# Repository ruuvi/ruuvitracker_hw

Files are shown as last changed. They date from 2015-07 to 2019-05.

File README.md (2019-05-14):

# RuuviTracker: Open-Source GPS/GSM Positioning Device

### NOTE: RuuviTracker has been rebranded to Ruuvi Node. This repository will be kept online for historical reasons.

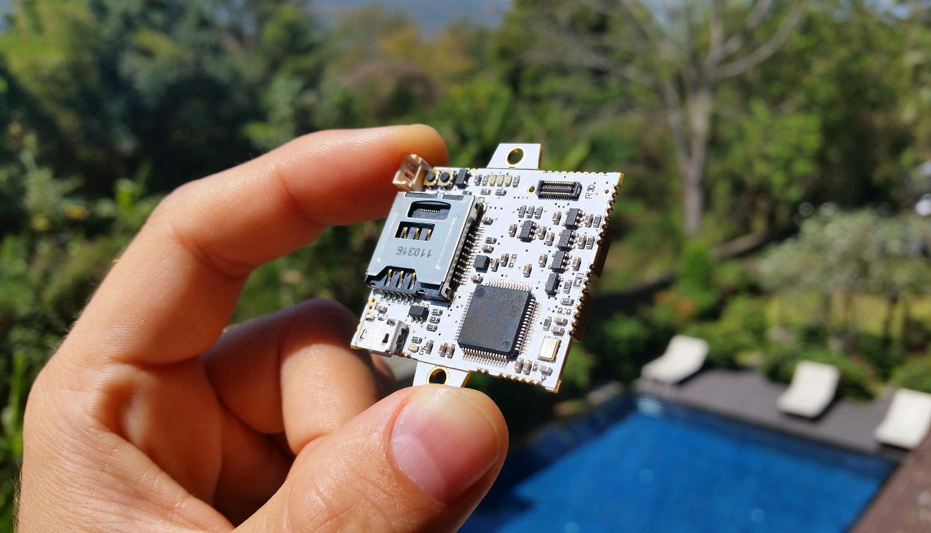
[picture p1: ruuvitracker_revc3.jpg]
RuuviTracker (http://ruuvi.com)


Latest hardware version is Rev.C3. First one was Rev.A1 and then Rev.B1 came out. And after that, Rev.C1 and Rev.C2. Revisions A, B and C are completely different devices.

All the design files are licensed under Attribution-ShareAlike 4.0 International (CC BY-SA 4.0). Copyright Lauri Jämsä, Ruuvi Innovations Ltd. Neither the name of the RuuviTracker nor the names of its contributors may be used to endorse or promote products derived from this project without specific prior written permission. While unofficial products should not have "Ruuvi" in their name, it's okay to describe your product in relation to the Ruuvi projects. For more info, drop us a line: license@ruuvi.com.

https://ruuvi.com

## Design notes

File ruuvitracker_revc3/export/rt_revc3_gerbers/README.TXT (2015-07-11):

Board: RuuviTracker Rev.C3

Board Size: 38.50 x 33.40mm
Material: FR4 High Tg 135C
Layers: 6
Silkscreen: Top & Bottom (black)
Solder masks: Top & Bottom (white)
Plating: Immersion Gold (or HASL if it's easier to assemble)
Thickness: 1.0mm !
Copper thickness: 35um
Paneling (you can decide what's best for you, this is just a suggestion. However, v-cuts are required):
3x2 (v-cuts + routing, see rt_revc2_paneling_info.pdf for help):
 __ __ __ 
|__|__|__|
|__|__|__|

Leadless solderpaste not required. More important that the yeld is 100%!

Minimum clearance: 0.10mm
Minimum trace thickness: 0.15mm
Minimum hole diameter: 0.30mm

Layer files (in correct order):
 
1. F_Cu (Top)
2. Inner4 (Sig1)
3. Inner3 (Sig2)
4. Inner2 (VDD)
5. Inner1 (GND)
6. B_Cu (Bottom)

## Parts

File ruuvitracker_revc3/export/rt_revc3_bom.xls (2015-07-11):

Id | Designator | Package | Quantity | Designation | Assembled? | Supplier and ref
1 | P12 | 005INCH_PINSTRIP_THRUHOLE_2PIN | 1 | 5V_IN | NO
2 | K1 | 53047-0310_3PIN_THRU | 1 | BATTERY |  | 53047-0310 | https://fi.mouser.com/Search/ProductDetail.aspx
3 | P5 | 005INCH_PINSTRIP_THRUHOLE_2PIN | 1 | GSM_SPK | NO
4 | P6 | 005INCH_PINSTRIP_THRUHOLE_2PIN | 1 | GSM_MIC | NO
5 | C1,C2,C3,C4,C5,C7 | SMD_0603_RT | 6 | 220n |  | VJ0603V224MXJPW1BC | http://fi.mouser.com/ProductDetail/Vishay-Vitramon/VJ0603V224MXJPW1BC/
6 | C6,C8,C9,C10,C11,C12,C13,C14,C15,C16,C17,C25,C27,C28,C29,C30,C31 | SMD_0603_RT | 17 | 2u2 |  | GRM188R61A225KE34D | http://fi.mouser.com/ProductDetail/Murata-Electronics/GRM188R61A225KE34D/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
7 | C18,C19 | TANTALUM_D_E_2917 | 2 | 680u |  | TPSE687M006R0045 | https://fi.mouser.com/Search/ProductDetail.aspx
8 | C20 | SMD_0603_RT | 1 | GPSCAP1 | NO
9 | C21 | SMD_0603_RT | 1 | GSMCAP1 | NO
10 | C22 | SMD_0603_RT | 1 | GPSCAP2 | NO
11 | C23 | SMD_0603_RT | 1 | GSMCAP2 | NO
12 | C24,C26 | SMD_0603_RT | 2 | 10p |  | VJ0603A100JXACW1BC | https://fi.mouser.com/Search/ProductDetail.aspx
13 | D1 | LED_SMD-0603 | 1 | LED_RED |  | VLMO1300-GS08 | http://fi.mouser.com/ProductDetail/Vishay/VLMO1300-GS08/
14 | D2,D3 | LED_SMD-0603 | 2 | LED_GREEN |  | VLMG1300-GS08 | http://fi.mouser.com/ProductDetail/Vishay/VLMG1300-GS08/
15 | D4 | LED_SMD-0603 | 1 | LED_CHG |  | VLMS1300-GS08 | http://fi.mouser.com/ProductDetail/Vishay-Semiconductors/VLMS1300-GS08/
16 | J1 | MICROUSB_B_10118192-0001LF | 1 | USB_MICRO_B |  | 10118192-0001LF | https://fi.mouser.com/Search/ProductDetail.aspx
17 | Q1 | SOT23-GDS | 1 | MOSFET_P |  | NX2301P,215 | https://fi.mouser.com/Search/ProductDetail.aspx
18 | R1,R2,R3,R4,R13 | SMD_0603_RT | 5 | 47k |  | ERJ-3EKF4702V | http://fi.mouser.com/ProductDetail/Panasonic/ERJ-3EKF4702V/
19 | R5,R6,R17 | SMD_0603_RT | 3 | 10 |  | ERJ-3GEYJ100V | http://fi.mouser.com/ProductDetail/Panasonic/ERJ-3GEYJ100V/
20 | R7,R22 | SMD_0603_RT | 2 | 2k |  | ERJ-3GEYJ202V | http://fi.mouser.com/ProductDetail/Panasonic/ERJ-3GEYJ202V/
21 | R8,R9,R10,R21 | SMD_0603_RT | 4 | 330 |  | ERJ-3GEYJ331V | http://fi.mouser.com/ProductDetail/Panasonic/ERJ-3GEYJ331V/?qs=sGAEpiMZZMu61qfTUdNhGzRxdwze5h8ZXotD4TVKeq8%3d
22 | R11,R12,R23,R24 | SMD_0603_RT | 4 | 4k7 |  | ERJ-3GEYJ472V | http://fi.mouser.com/ProductDetail/Panasonic/ERJ-3GEYJ472V/?qs=sGAEpiMZZMvdGkrng054txqI5fKHz4ddS7gybnWqBSI%3d
23 | R14, C32 | SMD_0603_RT | 1 | NA | NO
24 | R18 | SMD_0603_RT | 1 | GPSRES (0ohm) |  | RK73Z1JTTD | http://fi.mouser.com/ProductDetail/KOA-Speer/RK73Z1JTTD/
25 | R19 | SMD_0603_RT | 1 | GSMRES1 | NO
26 | R20 | SMD_0603_RT | 1 | GSMRES2 | NO
27 | SW1 | SKSGPAE010 | 1 | PUSH_BUTTON |  | SKSGPAE010 | https://fi.mouser.com/Search/ProductDetail.aspx
28 | U1 | LQFP-64 | 1 | STM32F10XXX_LQFP64 |  | STM32F405RGT6 | https://fi.mouser.com/Search/ProductDetail.aspx
29 | U3 | DFN_10PIN_2X2MM | 1 | MMA8652FC |  | MMA8652FCR1 | https://fi.mouser.com/Search/ProductDetail.aspx
30 | U7 | SOT23-6 | 1 | TPD2S017 |  | TPD2S017DBVR | https://fi.mouser.com/Search/ProductDetail.aspx
31 | X1 | ABM8G_3_2X2_5MM_4PIN_CRYSTAL | 1 | 8-24MHZ |  | FA-238 16.0000MB-K3 | http://fi.mouser.com/ProductDetail/Epson-Toyocom/FA-238-160000MB-K3/
32 | P7 | 005INCH_PINSTRIP_THRUHOLE_1PIN | 1 | GSM_ANT | NO
33 | U2 | SIM968_RECT | 1 | SIM968 |  | SIM968
34 | P2 | UFL-R-SMT | 1 | GPS_CONN |  | General U.FL SMD
35 | P3 | UFL-R-SMT | 1 | GSM_CONN |  | General U.FL SMD
36 | P8 | 1MM_THRUHOLE_1PIN | 1 | ALIGNMENT | NO
37 | U9 | COMBO_CARDSLOT_MES3051_OPTIMIZED | 1 | MICROSD_SIM_COMBO |  | AIO2X-21605BT00 (Kingfont)
38 | U4,U5,U6,U11 | SOT23-5 | 4 | TPS783XX |  | TPS78330DDCR | https://fi.mouser.com/Search/ProductDetail.aspx
39 | U8 | SOT23-5 | 1 | MCP73831 |  | MCP73831T-2ACI/OT | https://fi.mouser.com/Search/ProductDetail.aspx
40 | P4,P9,P10,P11 | TP_SMD_08MM | 4 | FIDU | NO
41 | P13,P14,P15,P16,P17,P18,P19,P20,P21,P22,P23,P24,P25,P26,P27,P28,P29,P30,P31,P32,P33,P34,P35,P36,P37,P38,P39,P40,P41,P42,P43,P44,P45,P46,P47 | 005INCH_PINSTRIP_THRUHOLE_1PIN | 35 | CONN_1 | NO
43 | SJ2 | SOLDER_JUMPER_2_PASTE12 | 1 | SOLDER_JUMPER_2_PASTE1&2 | NO
44 | SJ3,SJ1 | SOLDER_JUMPER_3_PASTE12 | 2 | SOLDER_JUMPER_3_PASTE1&2 | NO
45 | P48,P49 | 3MM_PLATED_HOLE | 2 | HOLE | NO
46 | P1 | DF37NB-24DS-04V | 1 | IPROTOXI_CONN |  | DF37NB-24DS-0.4V(51) | https://fi.mouser.com/Search/ProductDetail.aspx
47 | G*** | RUUVITRACKER_LOGO_035INCH_TOPMASK | 1 | RUUVITRACKER_LOGO_035INCH_TOPMASK | NO
45 | SW2 | SKSGPAE010 | 1 | BOOT0_BUT |  | SKSGPAE010

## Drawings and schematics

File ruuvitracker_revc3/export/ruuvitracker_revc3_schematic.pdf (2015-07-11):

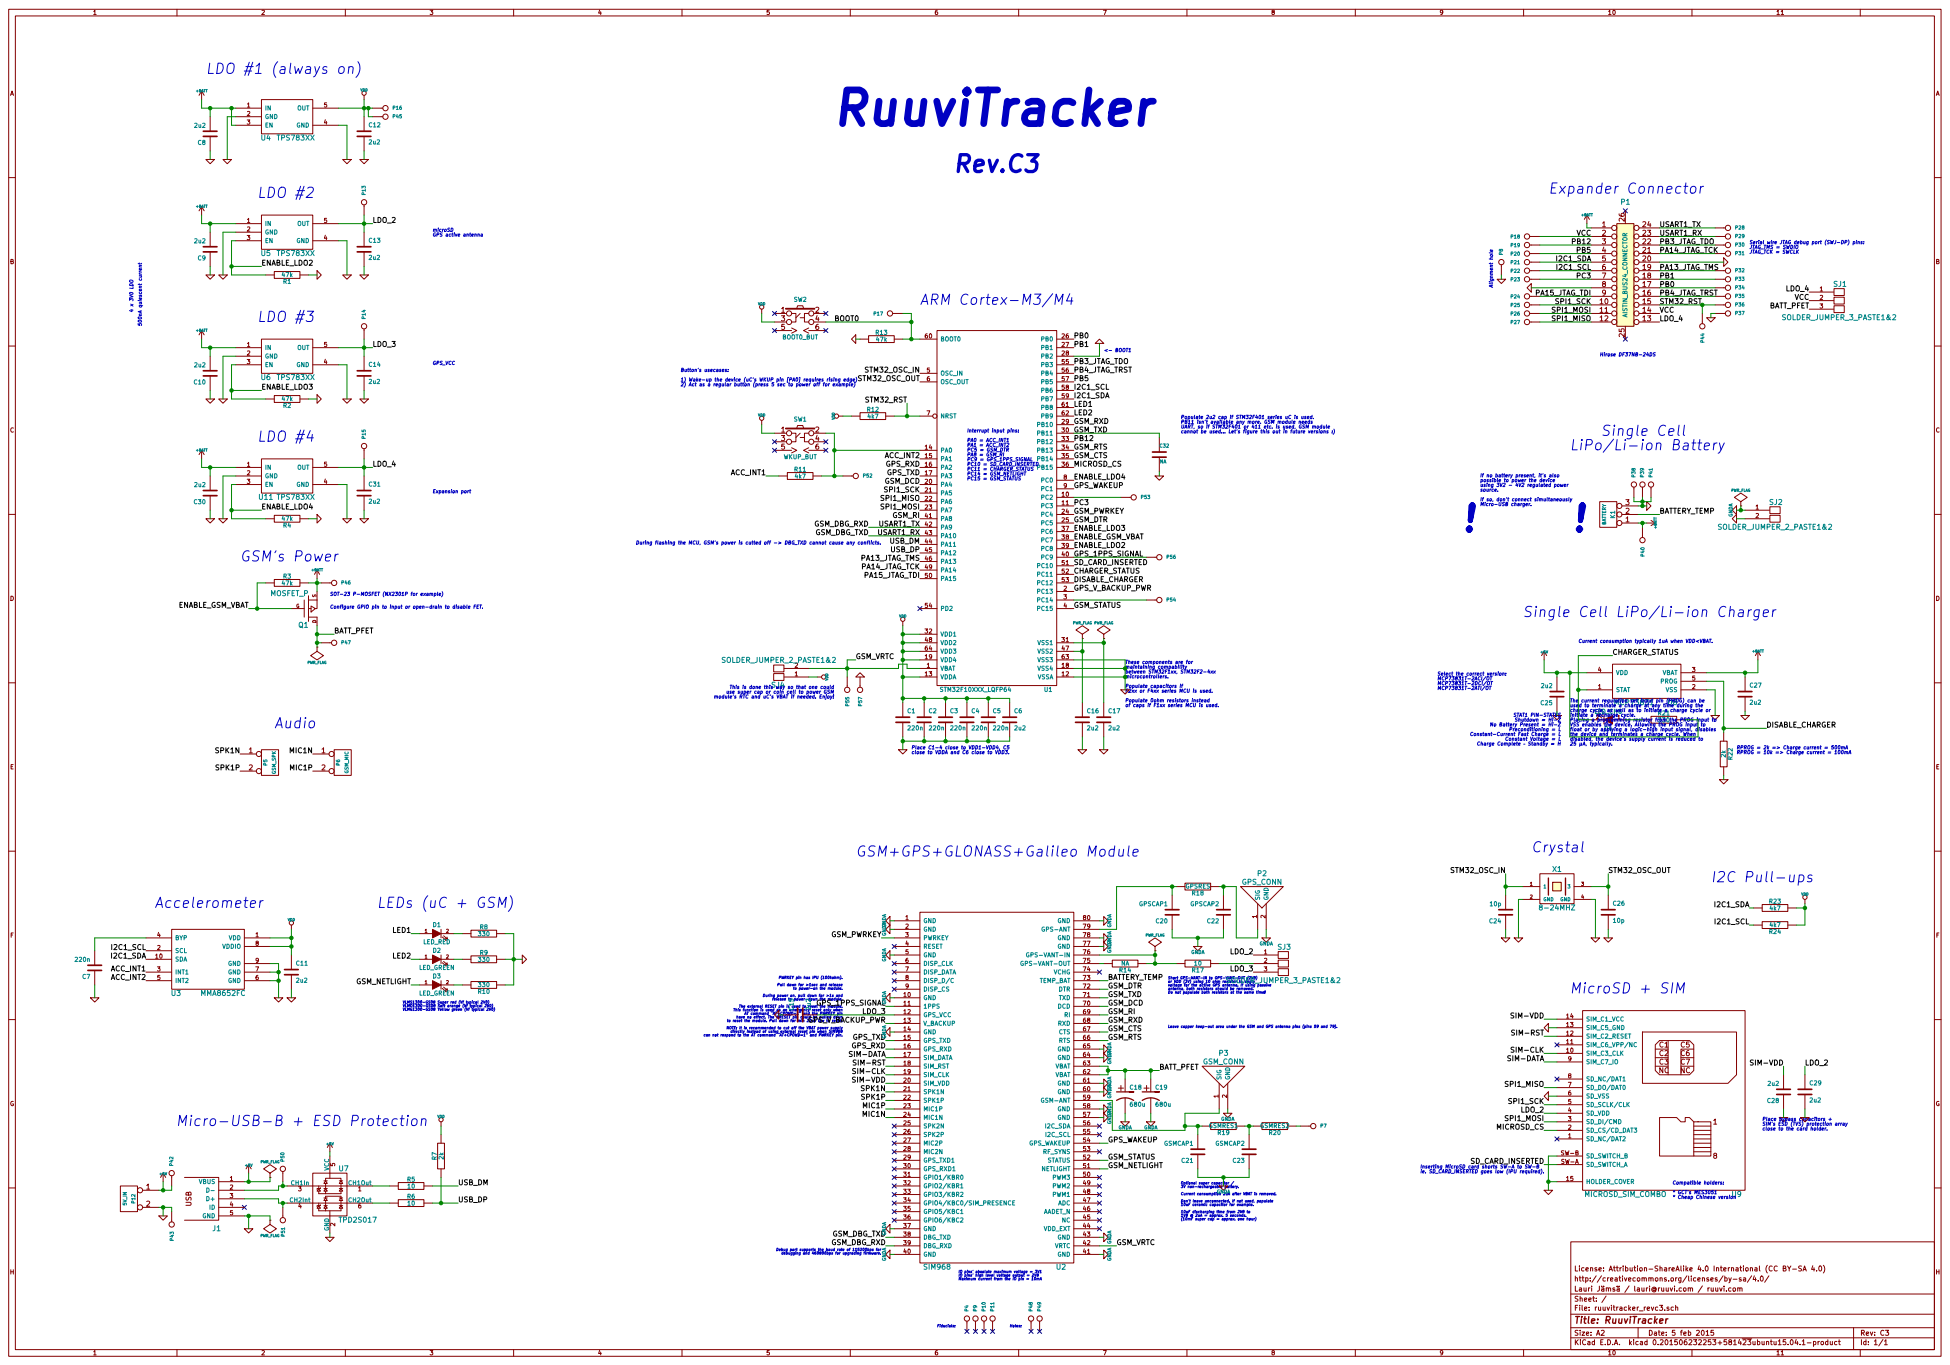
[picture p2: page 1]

SOT-23 P-MOSFET (NX2301P for example) LDO #2

LDO_2
microSD GPS active antenna GPS_VCC

VCC P8 Alignment hole Select the correct version: MCP73831T-2ACI/OT MCP73831T-2DCI/OT MCP73831T-2ATI/OT P4P9P10 P11

Serial wire JTAG debug port (SWJ-DP) pins: JTAG_TMS = SWDIO

4k7 BOOT0
close to VDDA and C6 close to VDD3. ACC_INT2

Populate 2u2 cap if STM32F401 series uC is used. PB11 isn't available any more. GSM module needs UART, so if STM32F401 or 411 etc. is used, GSM module

Single Cell
LiPo/Li-ion Battery 123 K1 BATTERY

GSM_RTS
GSM_CTS
of caps if F1xx series MCU is used. MICROSD_CS

If no battery present, it's also
possible to power the device
using 3V2 - 4V2 regulated power source.

If so, don't connect simultaneously Micro-USB charger.

Single Cell LiPo/Li-ion Charger

These components are for maintaining compability between STM32F1xx, STM32F2-4xx microcontrollers. Populate capacitors if F2xx or F4xx series MCU is used. Populate 0ohm resistors instead

use super cap or coin cell to power GSM

The current regulation set input pin (PROG) can be
used to terminate a charge at any time during the
charge cycle, as well as to initiate a charge cycle or
initiate a recharge cycle. Placing a programming resistor from the PROG input to VSS enables the device. Allowing the PROG input to

float or by applying a logic-high input signal, disables
the device and terminates a charge cycle. When
disabled, the devices supply current is reduced to

GSM+GPS+GLONASS+Galileo Module

VLMS1300-GS08 Super red (Vf typical 2V0) VLMO1300-GS08 Soft orange (Vf typical 2V0) VLMG1300-GS08 Yellow green (Vf typical 2V0) LEDs (uC + GSM)

antenna, both resistors should be removed. Do not populate both resistors at the same time! R14 NA GSM_DCD
BATTERY_TEMP
GSM_DTR
GSM_TXD

PWRKEY pin has IPU (100kohm). Pull down for >1sec and release

Short GPS-VANT-IN to GPS-VANT-OUT (2V8) or VDD (3V) using 10 ohm resistor to apply
voltage for the active GPS antenna. If using passive

to power-on the module. During power on, pull down for >1s and

release to power-down the module. The external RESET pin is used to reset the module. This function is used as an emergency reset only when AT command AT+CPOWD=1 and the PWRKEY pin

have no effect. The NRESET pin could be pulled down
to reset the module. Pull down for min 20us low to reset. NOTE: It is recommended to cut off the VBAT power supply directly instead of using external reset pin when SIM968

Leave copper keep-out area under the GSM and GPS antenna pins (pins 59 and 79). GSM_NETLIGHT

close to the card holder. C28

VDD Micro-USB-B + ESD Protection

Place bypass capacitors + SIM's ESD (TVS) protection array

Inserting MicroSD card shorts SW-A to SW-B

10uF ceramic capacitor for example. 10uF discharging time from 2V8 to

Debug port supports the baud rate of 115200bps for debugging and 460800bps for upgrading firmware.

IO pins' absolute maximum voltage = 3V1

License: Attribution-ShareAlike 4.0 International (CC BY-SA 4.0)
http://creativecommons.org/licenses/by-sa/4.0/
File: ruuvitracker_revc3.sch Sheet: / Lauri Jämsä / lauri@ruuvi.com / ruuvi.com

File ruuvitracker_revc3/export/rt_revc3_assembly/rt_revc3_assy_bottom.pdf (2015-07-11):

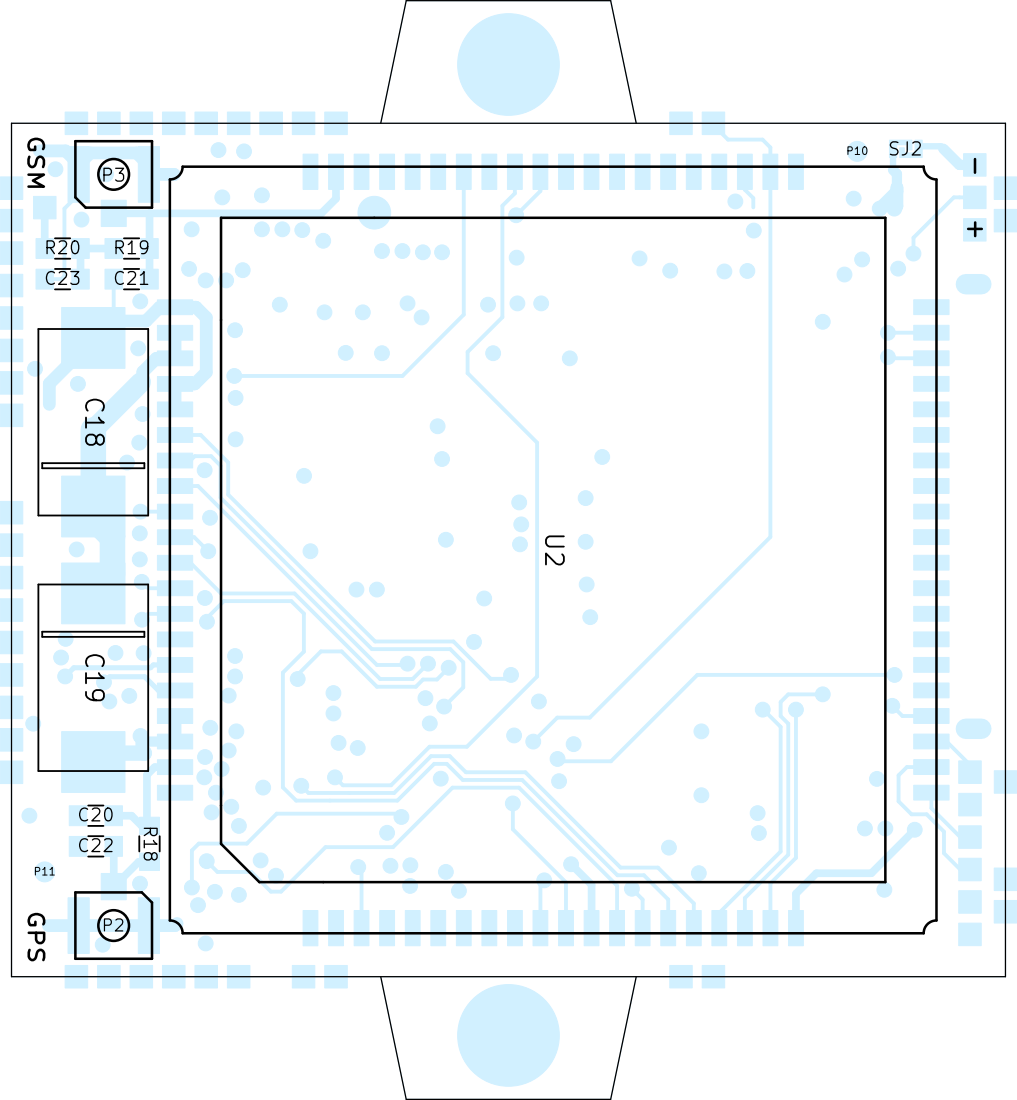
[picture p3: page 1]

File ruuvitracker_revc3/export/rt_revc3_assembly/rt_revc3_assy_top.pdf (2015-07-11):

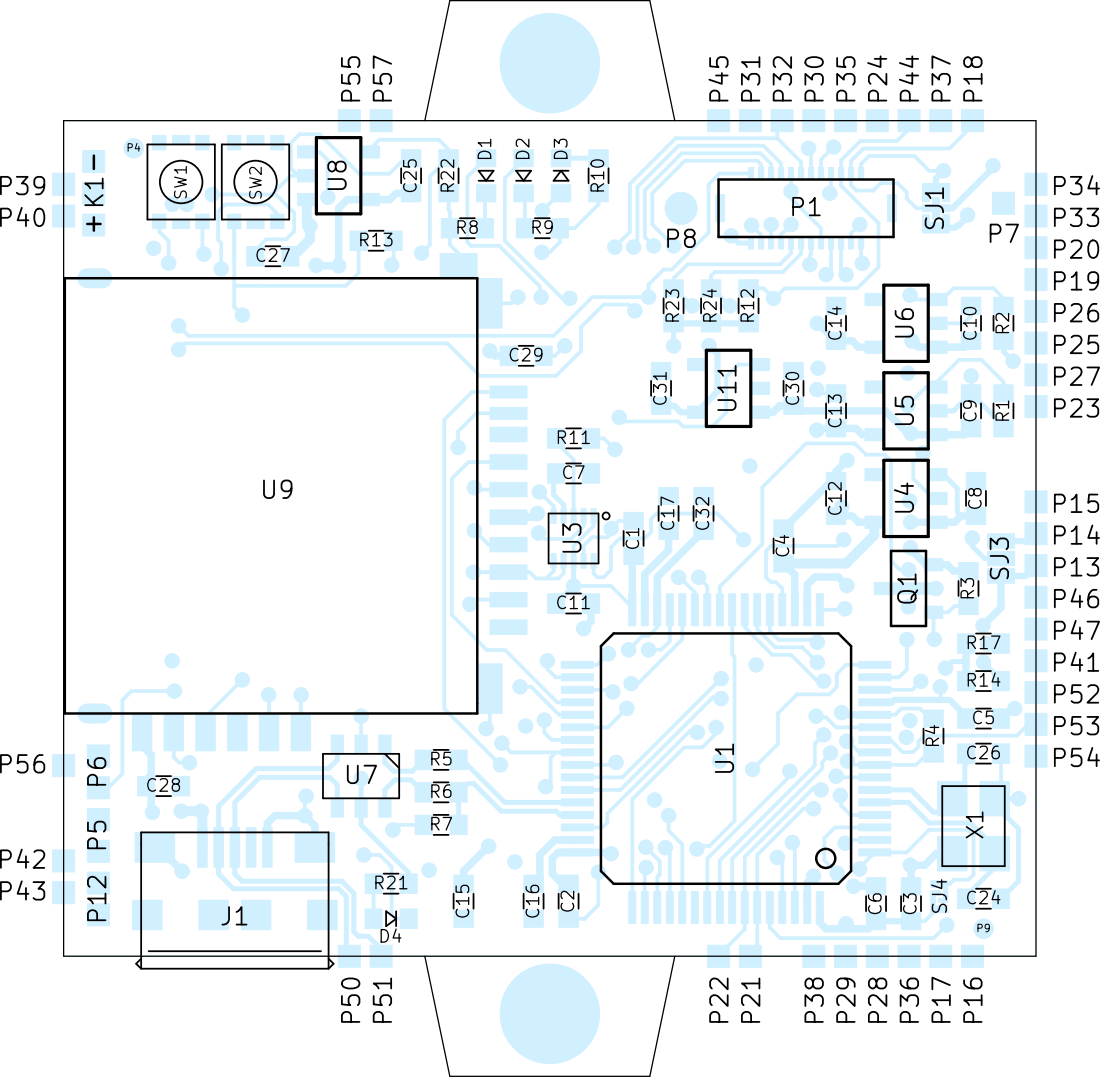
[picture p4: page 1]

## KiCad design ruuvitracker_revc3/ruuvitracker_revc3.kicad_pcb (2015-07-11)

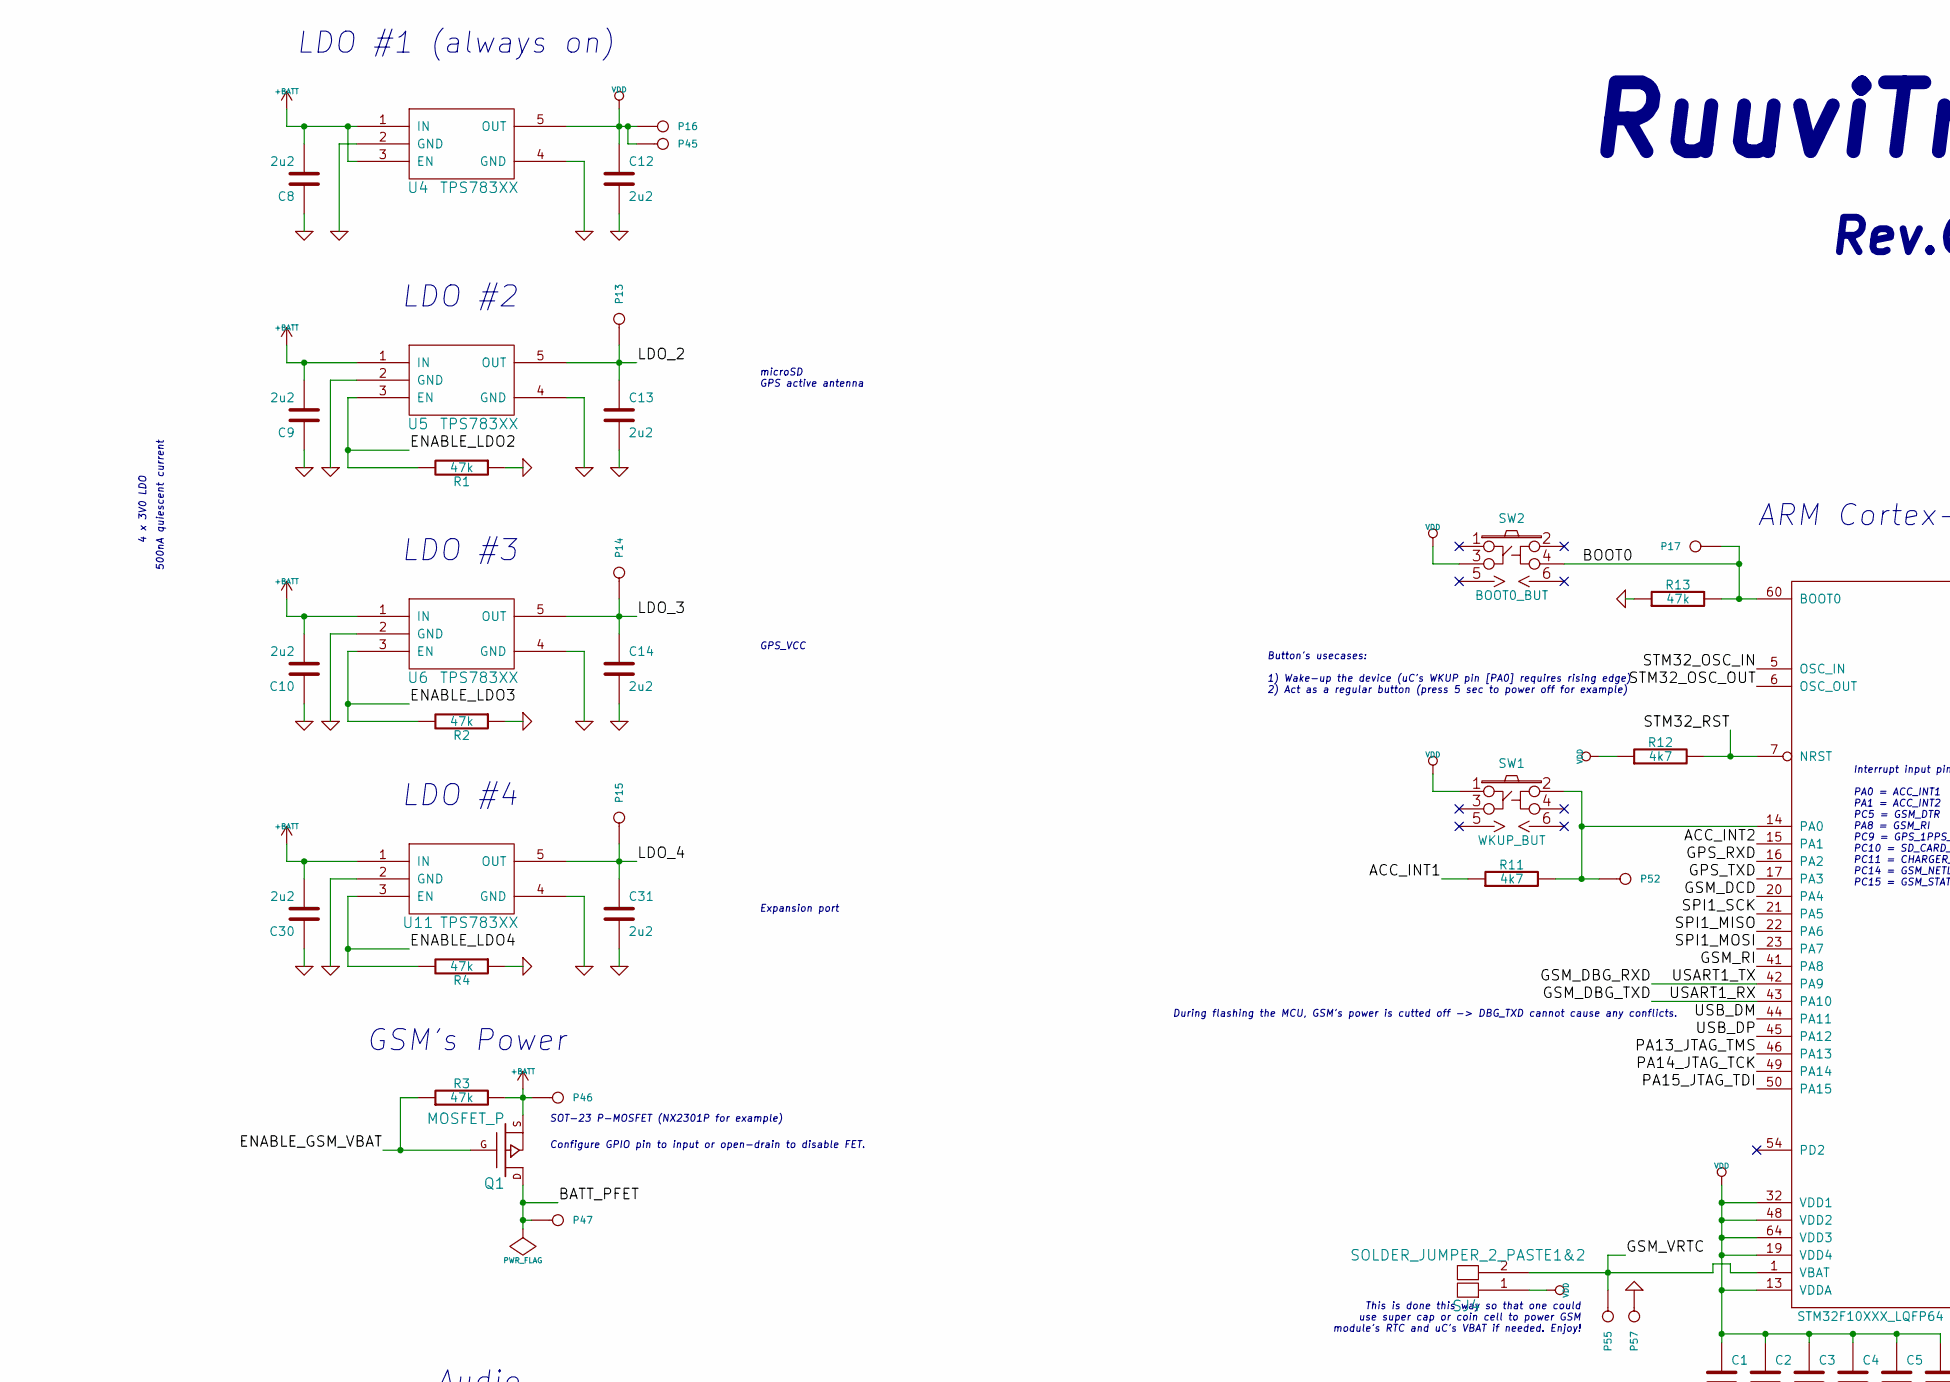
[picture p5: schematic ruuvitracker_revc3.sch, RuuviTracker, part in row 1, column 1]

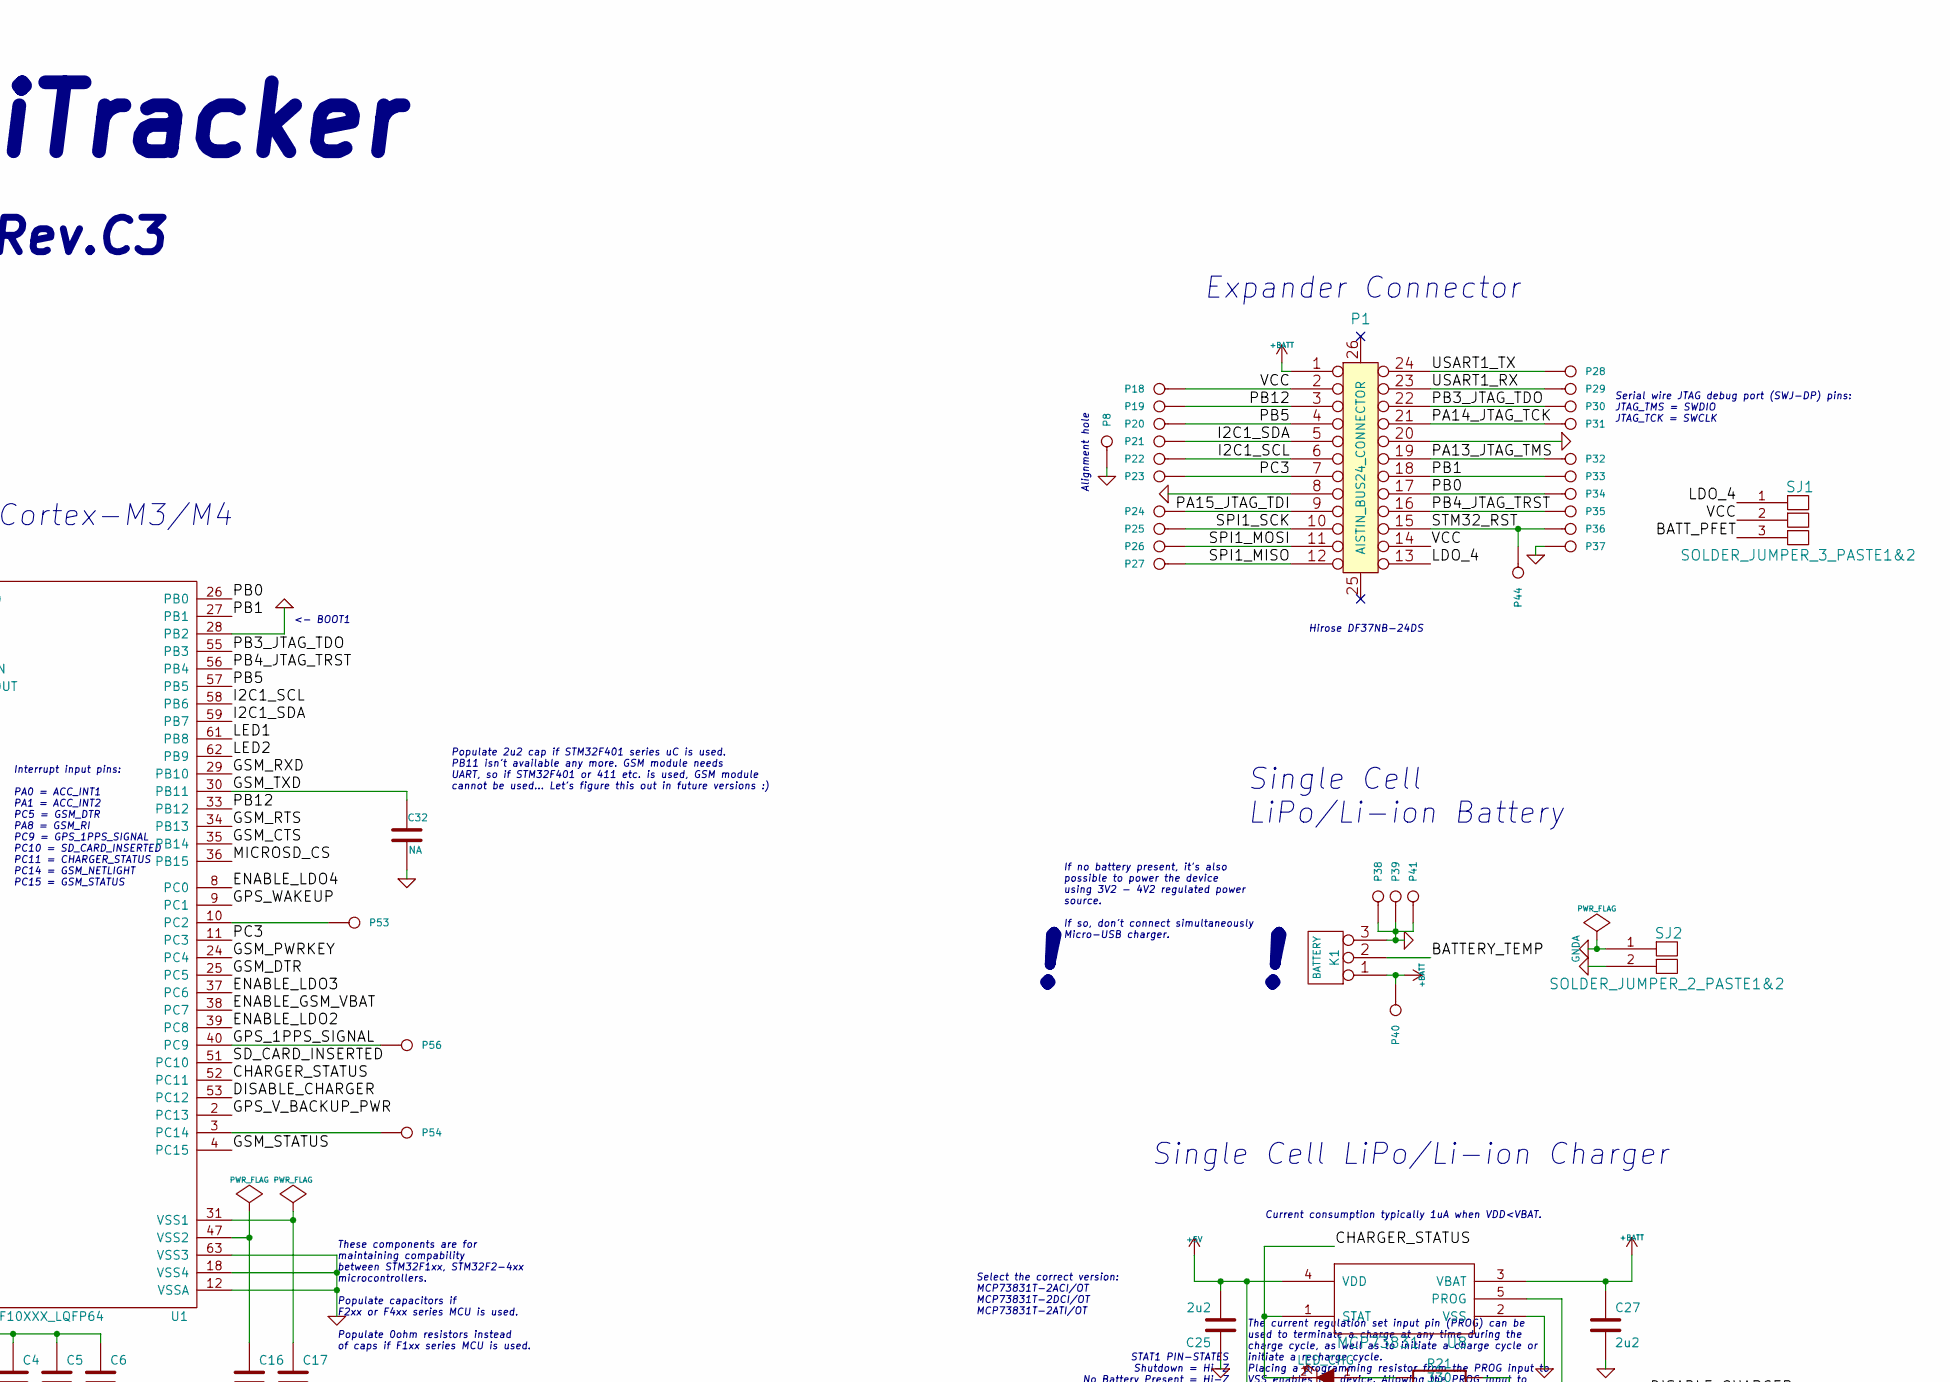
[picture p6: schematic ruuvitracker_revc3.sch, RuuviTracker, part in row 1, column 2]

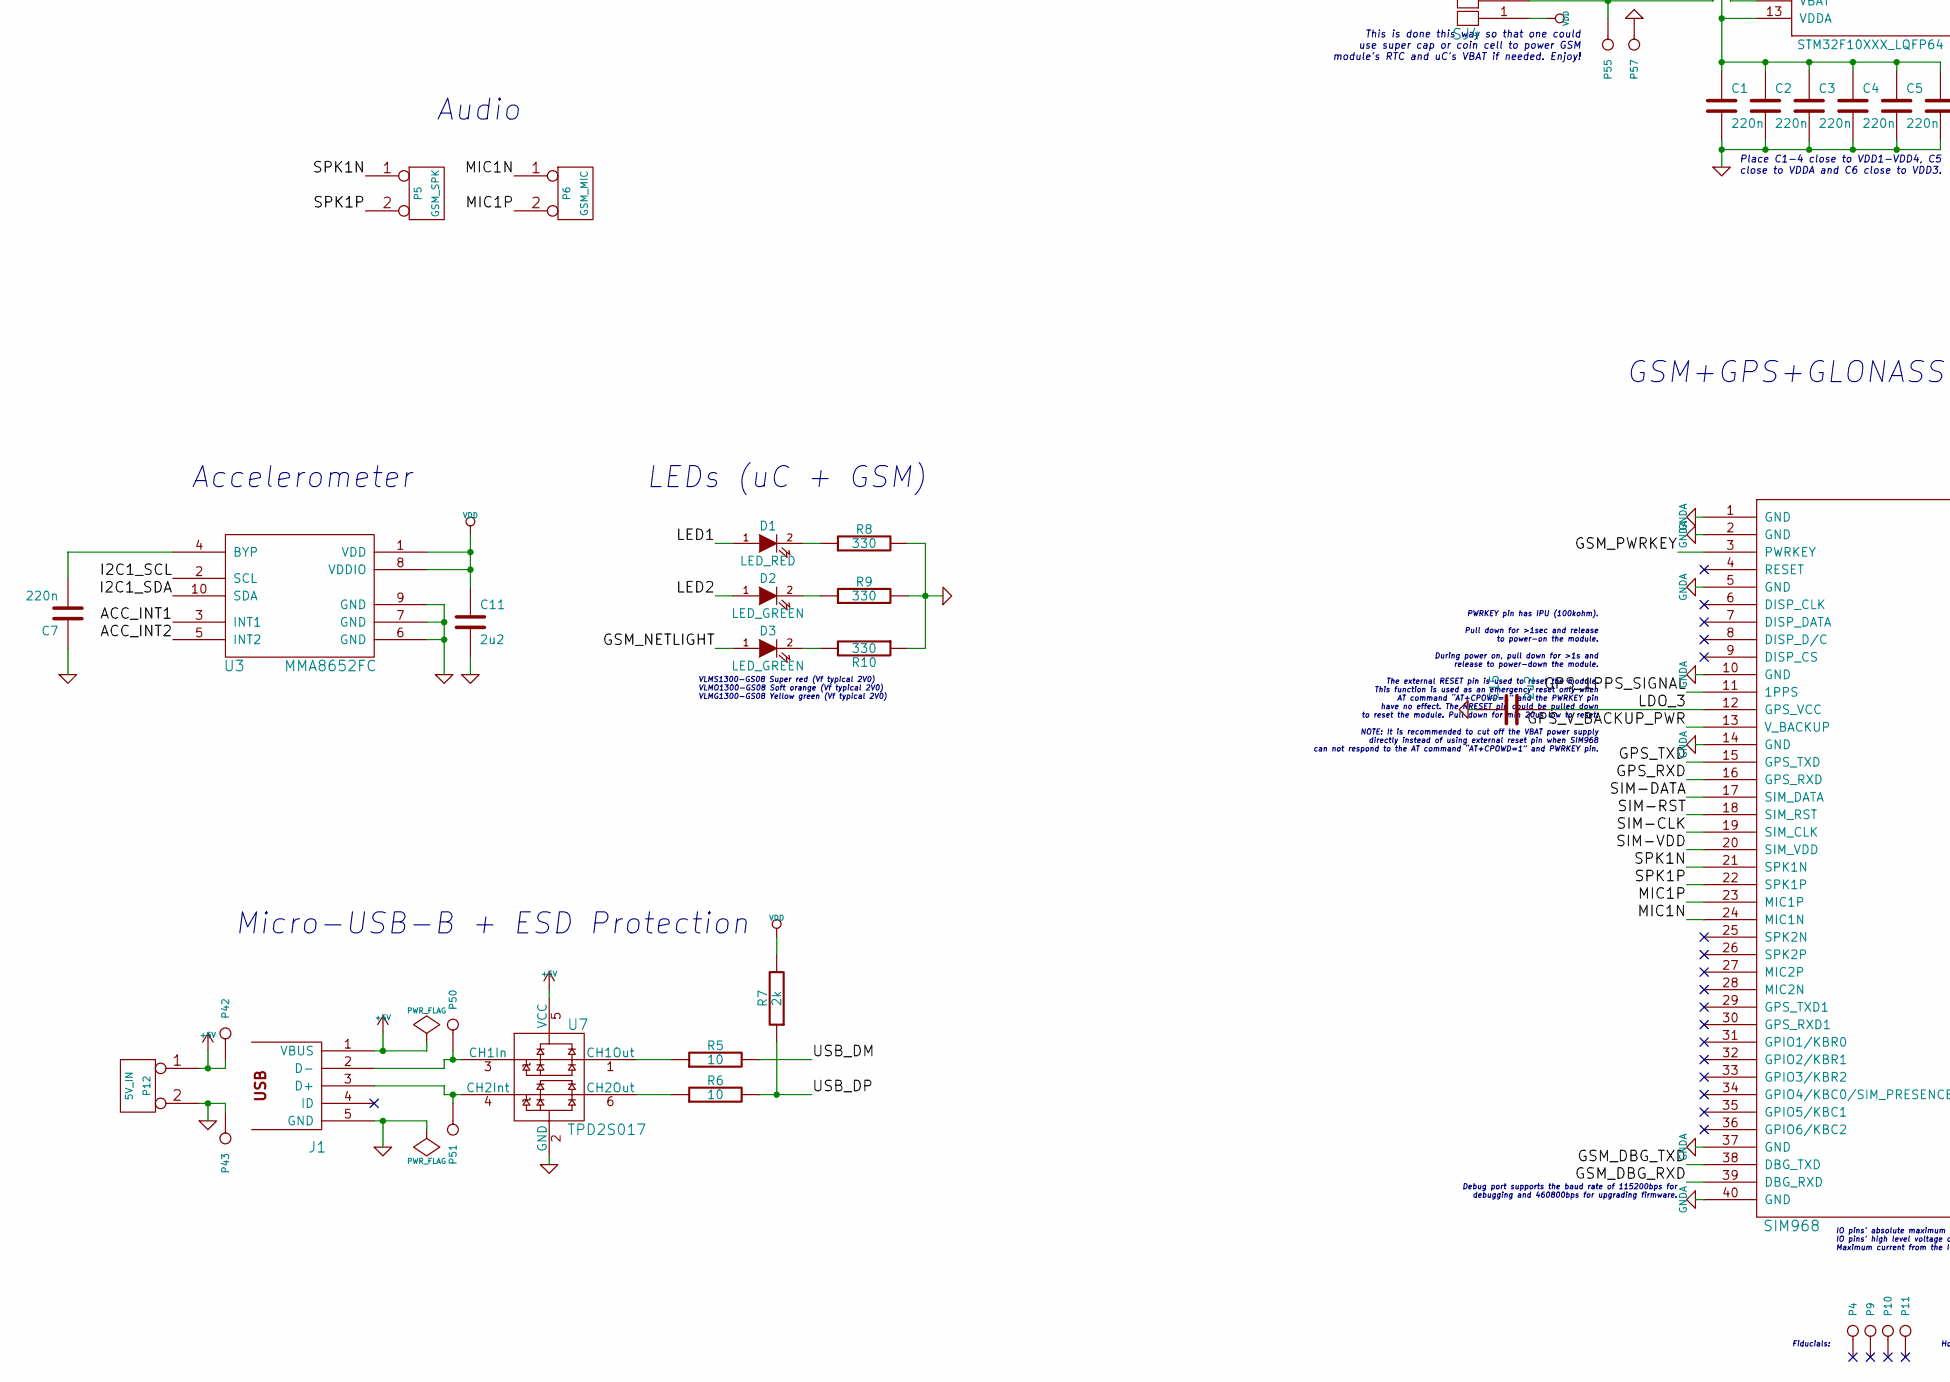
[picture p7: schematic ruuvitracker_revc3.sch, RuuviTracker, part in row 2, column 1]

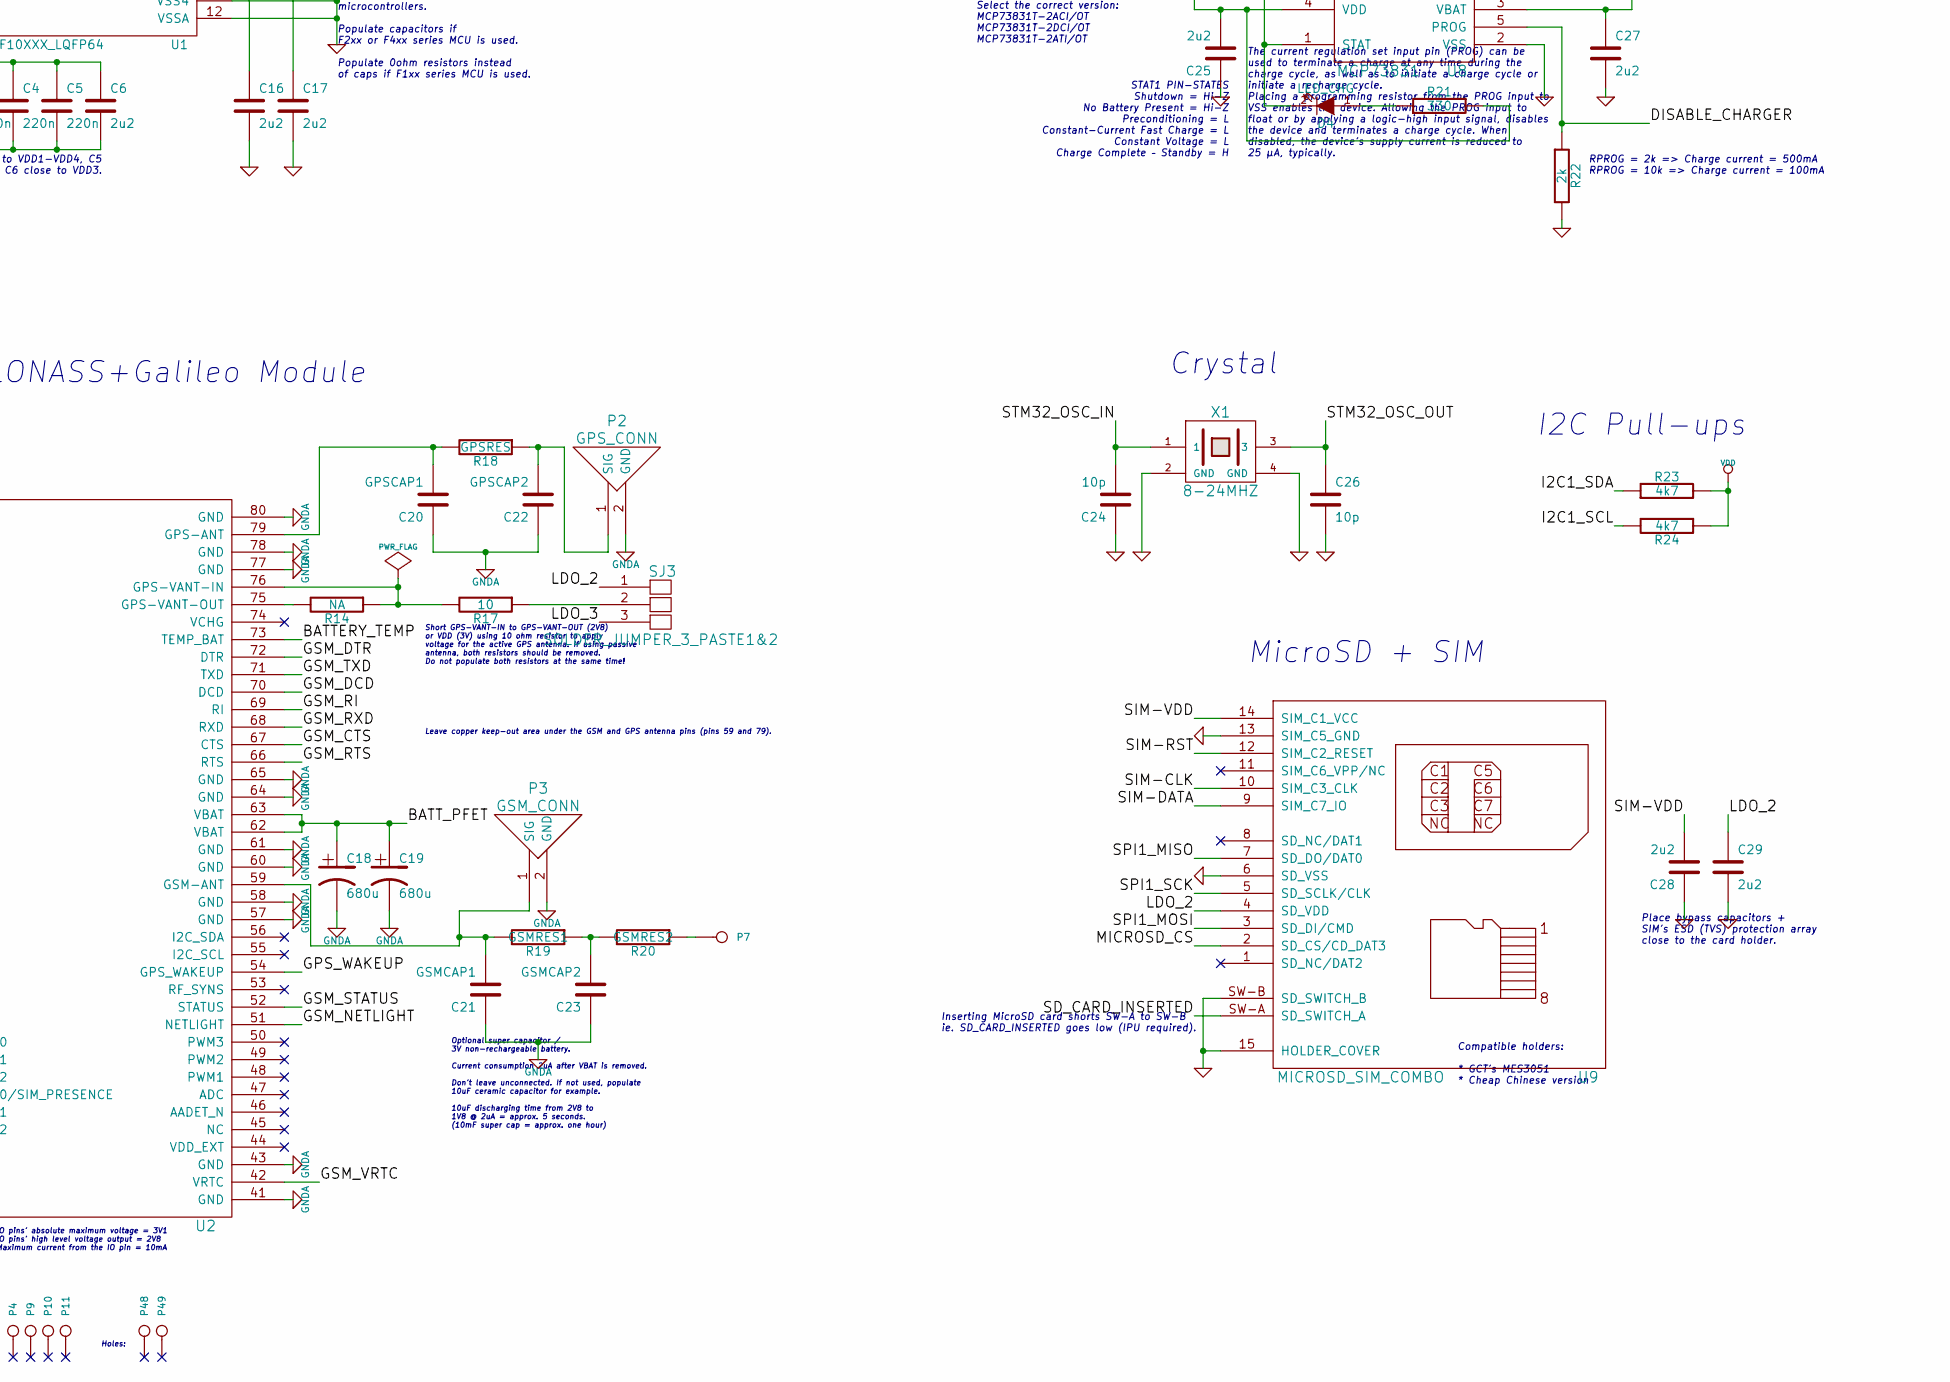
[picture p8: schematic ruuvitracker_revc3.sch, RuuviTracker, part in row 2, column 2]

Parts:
C1, C2, C3, C4, C5, C7: 220n
C6, C8, C9, C10, C11, C12, C13, C14, C15, C16, C17, C25, C27, C28, C29, C30, C31: 2u2
C18, C19: 680u
C20: GPSCAP1
C21: GSMCAP1
C22: GPSCAP2
C23: GSMCAP2
C24, C26: 10p
C32: NA
D1: LED_RED
D2, D3: LED_GREEN
D4: LED_CHG
J1: USB_MICRO_B
K1: BATTERY
P1: AISTIN_BUS24_CONNECTOR
P2: GPS_CONN
P3: GSM_CONN
P4, P9, P10, P11: FIDU
P5: GSM_SPK
P6: GSM_MIC
P7: GSM_ANT
P8: ALIGNMENT
P12: 5V_IN
P13, P14, P15, P16, P17, P18, P19, P20, P21, P22, P23, P24, P25, P26, P27, P28, P29, P30, P31, P32, P33, P34, P35, P36, P37, P38, P39, P40, P41, P42, P43, P44, P45, P46, P47, P50, P51, P52, P53, P54, P55, P56, P57: CONN_1
P48, P49: HOLE
Q1: MOSFET_P
R1, R2, R3, R4, R13: 47k
R5, R6, R17: 10
R7, R22: 2k
R8, R9, R10, R21: 330
R11, R12, R23, R24: 4k7
R14: NA
R18: GPSRES
R19: GSMRES1
R20: GSMRES2
SJ1, SJ3: SOLDER_JUMPER_3_PASTE1&2
SJ2, SJ4: SOLDER_JUMPER_2_PASTE1&2
SW1: WKUP_BUT
SW2: BOOT0_BUT
U1: STM32F10XXX_LQFP64
U2: SIM968
U3: MMA8652FC
U4, U5, U6, U11: TPS783XX
U7: TPD2S017
U8: MCP73831
U9: MICROSD_SIM_COMBO
X1: 8-24MHZ

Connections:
+5V: C25.2, J1.1 (VBUS), P12.1, P42.1, R21.2, U7.5 (VCC), U8.4 (VDD)
+BATT: C8.2, C9.2, C10.2, C27.1, C30.2, K1.1, P1.1, P40.1, P46.1, Q1.S, R3.2, U4.1 (IN), U4.3 (EN), U5.1 (IN), U6.1 (IN), U8.3 (VBAT), U11.1 (IN)
/ACC_INT1: R11.1, U3.3 (INT1)
/ACC_INT2: U1.15 (PA1), U3.5 (INT2)
/BATTERY_TEMP: K1.2 (PM), U2.73 (TEMP_BAT)
/BATT_PFET: C18.1, C19.1, P47.1, Q1.D, SJ1.3, U2.62 (VBAT), U2.63 (VBAT)
/BOOT0: P17.1, R13.2, SW2.4, U1.60 (BOOT0)
/CHARGER_STATUS: D4.2 (K), U1.52 (PC11), U8.1 (STAT)
/DISABLE_CHARGER: R22.1, U1.53 (PC12), U8.5 (PROG)
/ENABLE_GSM_VBAT: Q1.G, R3.1, U1.38 (PC7)
/ENABLE_LDO2: R1.2, U1.39 (PC8), U5.3 (EN)
/ENABLE_LDO3: R2.2, U1.37 (PC6), U6.3 (EN)
/ENABLE_LDO4: R4.2, U1.8 (PC0), U11.3 (EN)
/GPS_1PPS_SIGNAL: P56.1, U1.40 (PC9), U2.11 (1PPS)
/GPS_RXD: U1.16 (PA2), U2.16 (GPS_RXD)
/GPS_TXD: U1.17 (PA3), U2.15 (GPS_TXD)
/GPS_V_BACKUP_PWR: U1.2 (PC13), U2.13 (V_BACKUP)
/GPS_WAKEUP: U1.9 (PC1), U2.54 (GPS_WAKEUP)
/GSM_CTS: U1.35 (PB14), U2.67 (CTS)
/GSM_DBG_RXD: P1.24, P28.1, U1.42 (PA9), U2.39 (DBG_RXD)
/GSM_DBG_TXD: P1.23, P29.1, U1.43 (PA10), U2.38 (DBG_TXD)
/GSM_DCD: U1.20 (PA4), U2.70 (DCD)
/GSM_DTR: U1.25 (PC5), U2.72 (DTR)
/GSM_NETLIGHT: D3.1 (A), U2.51 (NETLIGHT)
/GSM_PWRKEY: U1.24 (PC4), U2.3 (PWRKEY)
/GSM_RI: U1.41 (PA8), U2.69 (RI)
/GSM_RTS: U1.34 (PB13), U2.66 (RTS)
/GSM_RXD: U1.29 (PB10), U2.68 (RXD)
/GSM_STATUS: U1.4 (PC15), U2.52 (STATUS)
/GSM_TXD: C32.1, U1.30 (PB11), U2.71 (TXD)
/GSM_VRTC: P55.1, SJ4.2, U1.1 (VBAT), U2.42 (VRTC)
/I2C1_SCL: P1.6, P22.1, R24.2, U1.58 (PB6), U3.2 (SCL)
/I2C1_SDA: P1.5, P21.1, R23.1, U1.59 (PB7), U3.10 (SDA)
/LDO_2: C13.1, C29.1, P13.1, SJ3.1, U5.5 (OUT), U9.4 (SD_VDD)
/LDO_3: C14.1, C15.2, P14.1, SJ3.3, U2.12 (GPS_VCC), U6.5 (OUT)
/LDO_4: C31.1, P1.13, P15.1, SJ1.1, U11.5 (OUT)
/LED1: D1.1 (A), U1.61 (PB8)
/LED2: D2.1 (A), U1.62 (PB9)
/MIC1N: P6.1, U2.24 (MIC1N)
/MIC1P: P6.2 (PM), U2.23 (MIC1P)
/MICROSD_CS: U1.36 (PB15), U9.2 (SD_CS/CD_DAT3)
/PA13_JTAG_TMS: P1.19, P32.1, U1.46 (PA13)
/PA14_JTAG_TCK: P1.21, P31.1, U1.49 (PA14)
/PA15_JTAG_TDI: P1.9, P24.1, U1.50 (PA15)
/PB0: P1.17, P34.1, U1.26 (PB0)
/PB1: P1.18, P33.1, U1.27 (PB1)
/PB3_JTAG_TDO: P1.22, P30.1, U1.55 (PB3)
/PB4_JTAG_TRST: P1.16, P35.1, U1.56 (PB4)
/PB5: P1.4, P20.1, U1.57 (PB5)
/PB12: P1.3, P19.1, U1.33 (PB12)
/PC3: P1.7, P23.1, U1.11 (PC3)
/SD_CARD_INSERTED: U1.51 (PC10), U9.SW-A (SD_SWITCH_A)
/SIM-CLK: U2.19 (SIM_CLK), U9.10 (SIM_C3_CLK)
/SIM-DATA: U2.17 (SIM_DATA), U9.9 (SIM_C7_IO)
/SIM-RST: U2.18 (SIM_RST), U9.12 (SIM_C2_RESET)
/SIM-VDD: C28.2, U2.20 (SIM_VDD), U9.14 (SIM_C1_VCC)
/SPI1_MISO: P1.12, P27.1, U1.22 (PA6), U9.7 (SD_DO/DAT0)
/SPI1_MOSI: P1.11, P26.1, U1.23 (PA7), U9.3 (SD_DI/CMD)
/SPI1_SCK: P1.10, P25.1, U1.21 (PA5), U9.5 (SD_SCLK/CLK)
/SPK1N: P5.1, U2.21 (SPK1N)
/SPK1P: P5.2 (PM), U2.22 (SPK1P)
/STM32_OSC_IN: C24.2, U1.5 (OSC_IN), X1.1
/STM32_OSC_OUT: C26.1, U1.6 (OSC_OUT), X1.3
/STM32_RST: P1.15, P36.1, P44.1, R12.2, U1.7 (NRST)
/USB_DM: R5.2, U1.44 (PA11)
/USB_DP: R6.2, R7.1, U1.45 (PA12)
/VCC: P1.2, P1.14, P18.1, SJ1.2
GND: C1.2, C2.2, C3.2, C4.2, C5.2, C6.2, C7.1, C8.1, C9.1, C10.1, C11.2, C12.2, C13.2, C14.2, C15.1, C16.2, C17.2, C24.1, C25.1, C26.2, C27.2, C28.1, C29.2, C30.1, C31.2, C32.2, J1.5 (GND), K1.3, P1.8, P1.20, P8.1, P12.2 (PM), P37.1, P38.1, P39.1, P41.1, P43.1, P57.1, R1.1, R2.1, R4.1, R8.2, R9.2, R10.1, R13.1, R22.2, SJ2.2, U1.12 (VSSA), U1.18 (VSS4), U1.28 (PB2), U1.63 (VSS3), U3.6 (GND), U3.7 (GND), U3.9 (GND), U4.2 (GND), U4.4 (GND), U5.2 (GND), U5.4 (GND), U6.2 (GND), U6.4 (GND), U7.2 (GND), U8.2 (VSS), U9.6 (SD_VSS), U9.13 (SIM_C5_GND), U9.15 (HOLDER_COVER), U9.SW-B (SD_SWITCH_B), U11.2 (GND), U11.4 (GND), X1.2 (GND), X1.4 (GND)
GNDA: C18.2, C19.2, C20.1, C21.1, C22.1, C23.1, P2.2 (GND), P3.2 (GND), SJ2.1, U2.1 (GND), U2.2 (GND), U2.5 (GND), U2.10 (GND), U2.14 (GND), U2.37 (GND), U2.40 (GND), U2.41 (GND), U2.43 (GND), U2.57 (GND), U2.58 (GND), U2.60 (GND), U2.61 (GND), U2.64 (GND), U2.65 (GND), U2.77 (GND), U2.78 (GND), U2.80 (GND)
unnamed: P52.1, R11.2, SW1.2, U1.14 (PA0)
unnamed: C16.1, U1.47 (VSS2)
unnamed: C17.1, U1.31 (VSS1)
unnamed: C20.2, R18.2, U2.79 (GPS-ANT)
unnamed: C22.2, P2.1 (SIG), R18.1
unnamed: R17.1, SJ3.2
unnamed: R14.2, U2.75 (GPS-VANT-OUT)
unnamed: R14.1, R17.2, U2.76 (GPS-VANT-IN)
unnamed: P53.1, U1.10 (PC2)
unnamed: P54.1, U1.3 (PC14)
unnamed: J1.3 (D+), P51.1, U7.4 (CH2Int)
unnamed: C21.2, P3.1 (SIG), R19.2, U2.59 (GSM-ANT)
unnamed: C23.2, R19.1, R20.2
unnamed: P7.1, R20.1
unnamed: R6.1, U7.6 (CH2Out)
unnamed: R5.1, U7.1 (CH1Out)
unnamed: J1.2 (D-), P50.1, U7.3 (CH1In)
unnamed: D3.2 (K), R10.2
unnamed: D1.2 (K), R8.1
unnamed: D2.2 (K), R9.1
unnamed: C7.2, U3.4 (BYP)
unnamed: D4.1 (A), R21.1
VDD: C1.1, C2.1, C3.1, C4.1, C5.1, C6.1, C11.1, C12.1, P16.1, P45.1, R7.2, R12.1, R23.2, R24.1, SJ4.1, SW1.1, SW2.3, U1.13 (VDDA), U1.19 (VDD4), U1.32 (VDD1), U1.48 (VDD2), U1.64 (VDD3), U3.1 (VDD), U3.8 (VDDIO), U4.5 (OUT)

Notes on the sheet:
Leave copper keep-out area under the GSM and GPS antenna pins (pins 59 and 79).
IO pins' absolute maximum voltage = 3V1 IO pins' high level voltage output = 2V8 Maximum current from the IO pin = 10mA
Optional super capacitor / 3V non-rechargeable battery. Current consumption 2uA after VBAT is removed. Don't leave unconnected. If not used, populate 10uF ceramic capacitor for example. 10uF discharging time from 2V8 to 1V8 @ 2uA = approx. 5 seconds. (10mF super cap = approx. one hour)
Short GPS-VANT-IN to GPS-VANT-OUT (2V8) or VDD (3V) using 10 ohm resistor to apply voltage for the active GPS antenna. If using passive antenna, both resistors should be removed. Do not populate both resistors at the same time!
PWRKEY pin has IPU (100kohm). Pull down for >1sec and release to power-on the module. During power on, pull down for >1s and release to power-down the module. The external RESET pin is used to reset the module. This function is used as an emergency reset only when AT command “AT+CPOWD=1” and the PW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
GSM+GPS+GLONASS+Galileo Module
These components are for maintaining compability between STM32F1xx, STM32F2-4xx microcontrollers. Populate capacitors if F2xx or F4xx series MCU is used. Populate 0ohm resistors instead of caps if F1xx series MCU is used.
Place C1-4 close to VDD1-VDD4, C5 close to VDDA and C6 close to VDD3.
<- BOOT1
ARM Cortex-M3/M4
Inserting MicroSD card shorts SW-A to SW-B ie. SD_CARD_INSERTED goes low (IPU required).
Compatible holders: * GCT's MES3051 * Cheap Chinese version
! !
If no battery present, it's also possible to power the device using 3V2 - 4V2 regulated power source. If so, don't connect simultaneously Micro-USB charger.
Place bypass capacitors + SIM's ESD (TVS) protection array close to the card holder.
Single Cell LiPo/Li-ion Battery
MicroSD + SIM
I2C Pull-ups
VLMS1300-GS08 Super red (Vf typical 2V0) VLMO1300-GS08 Soft orange (Vf typical 2V0) VLMG1300-GS08 Yellow green (Vf typical 2V0)
LEDs (uC + GSM)
Single Cell LiPo/Li-ion Charger
STAT1 PIN-STATES Shutdown = Hi-Z No Battery Present = Hi-Z Preconditioning = L Constant-Current Fast Charge = L Constant Voltage = L Charge Complete – Standby = H
The current regulation set input pin (PROG) can be used to terminate a charge at any time during the charge cycle, as well as to initiate a charge cycle or initiate a recharge cycle. Placing a programming resistor from the PROG input to VSS enables the device. Allowing the PROG input to float or by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
RPROG = 2k => Charge current = 500mA RPROG = 10k => Charge current = 100mA
Accelerometer
Crystal
Debug port supports the baud rate of 115200bps for debugging and 460800bps for upgrading firmware.
Serial wire JTAG debug port (SWJ-DP) pins: JTAG_TMS = SWDIO JTAG_TCK = SWCLK
500nA quiescent current
LDO #1 (always on)
Audio
Micro-USB-B + ESD Protection
GSM's Power
SOT-23 P-MOSFET (NX2301P for example)
LDO #2
Configure GPIO pin to input or open-drain to disable FET.
Button's usecases: 1) Wake-up the device (uC's WKUP pin [PA0] requires rising edge) 2) Act as a regular button (press 5 sec to power off for example)
RuuviTracker
Rev.C3
Current consumption typically 1uA when VDD<VBAT.

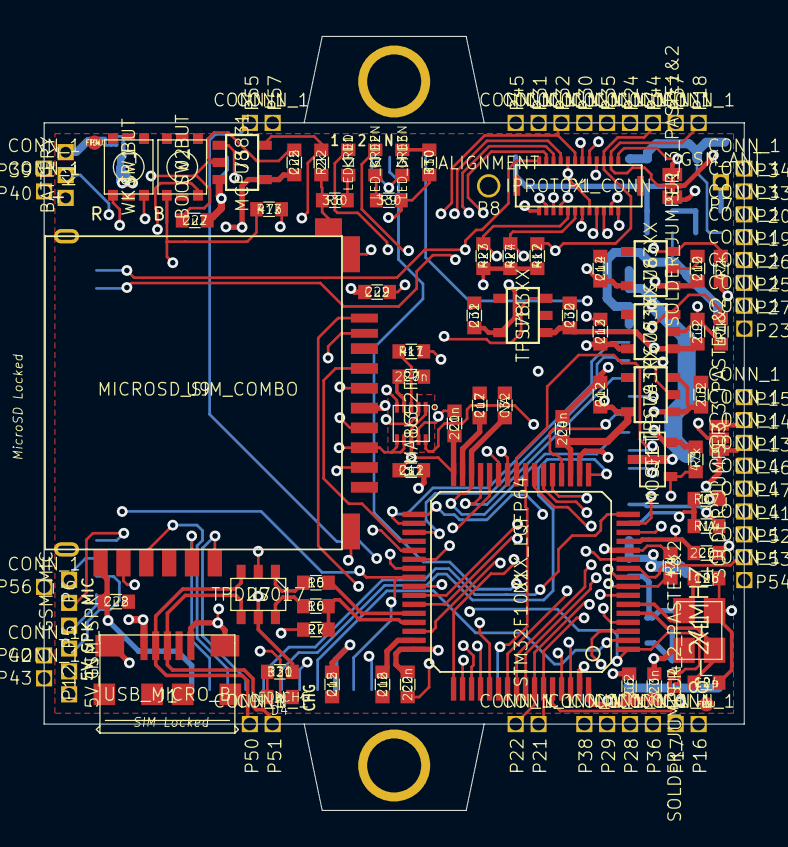
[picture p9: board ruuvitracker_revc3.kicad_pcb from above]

Board: 6 copper layers, 38.9 x 33.4 mm, 135 parts (0 on the bottom side), 92 nets.

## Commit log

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2012-01-12 Added some logic to detect Micro-USB charger properly + some minor bug fixes.
    [ruuvitracker.sch]
2012-01-14 Some fixes to schematic, created new footprints and .brd file.
    Fixed:
    - Mirrored MicroSD schematic component
    Created:
    - Over 10 new footprints
    - .cmp file
    - .brd file
    [ruuvitracker.brd, ruuvitracker.sch]
2012-01-14 Modified few footprints, continued component placement.
    [ruuvitracker.brd]
2012-01-14 Component placement almost ready. PCB shrinked from 55x37mm to 50x30mm.
    [ruuvitracker.brd, ruuvitracker.sch]
2012-01-14 Component placement almost ready. PCB shrinked from 55x37mm to 50x37mm.
    [ruuvitracker.brd, ruuvitracker.sch]
2012-01-15 Added two 3mm holes. No routing done yet. Component placement almost ok.
    [ruuvitracker.brd, ruuvitracker.sch]
2012-01-15 Almost all traces routed. Still 2-layer board, jei! :-)
    [ruuvitracker.brd, ruuvitracker.sch]
2012-01-16 All traces routed and DRC passed!
    [ruuvitracker.brd]
2012-01-17 PCB 99% ready. Add .gitignore.
    [ruuvitracker.brd]
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2012-01-17 Modified component references on PCB (better alignment).
    [ruuvitracker.brd, ruuvitracker.sch]
2012-01-18 Added dimensions of the board.
    [ruuvitracker.brd]
2012-01-19 Added kicad_lib folder with few 3D models.
    [ruuvitracker.brd]
2012-01-19 Fixed 3D models' paths.
    [ruuvitracker.brd]
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2012-01-19 Fixed 3D model paths...
    [ruuvitracker.brd]
2012-01-19 Fixed eeschema library problems.
    [ruuvitracker.sch]
2012-01-22 New 3D models for card slot and MicroUSB connector.
    [ruuvitracker.brd]
2012-01-23 Added 3D model for crystal and fixed card slot's 3D model.
    [ruuvitracker.brd]
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2012-09-27 New MCU and totally new schema layout.
    [ruuvitracker.sch]
2012-10-20 Add new charger IC
    [ruuvitracker.sch]
2012-11-15 Add MEMS microphone and some minor mods.
    [ruuvitracker.sch]
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2012-11-25 New LED layout and some other minor mods.
    [ruuvitracker.sch]
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2012-12-08 New pwr switch and expander connector
    [ruuvitracker.sch]
2012-12-08 Remove speaker's and mic's caps to save space
    [ruuvitracker.sch]
2012-12-08 Add external audio amp
    [ruuvitracker.sch]
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2012-12-18 New USB OTG EMI protection IC
    [ruuvitracker.sch]
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2012-12-20 Another ESD IC replacement
    [ruuvitracker.sch]
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2012-12-23 Some thinking about pinouts
    [ruuvitracker.sch]
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2012-12-23 Little more pin arrangement
    [ruuvitracker.sch]
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2012-12-24 First final annotated RevB schematics version
    [ruuvitracker.sch]
2012-12-24 Add alternative voltage source for GPS active antennas
    [ruuvitracker.sch]
2012-12-24 Some corrections for texts
    [ruuvitracker.sch]
2012-12-24 Change IO Expander's pinout
    [ruuvitracker.sch]
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2012-12-26 Replace EEPROM IC
    [ruuvitracker.sch]
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2012-12-26 Replace gyroscope IC
    [ruuvitracker.sch]
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2012-12-28 Add 1Mohm pull-down resistors to ensure known pinstates during bootloader's detection phase.
    [ruuvitracker.sch]
2012-12-28 Add batt voltage divider and P-MOSFETs for GSM and SD
    [ruuvitracker.sch]
2012-12-29 Small fixes (pwr switch, fet gates' io pins etc.)
    [ruuvitracker.sch]
2012-12-29 Add P-MOSTET to enable SYSTEM_LOAD only using pwr switch
    [ruuvitracker.sch]
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2012-12-29 Replace 26pin expander#1 with 26x2 expander
    [ruuvitracker.sch]
2012-12-30 Made according TI's specs (paste layer's clearance 0,01mm smaller [+0,01mm instead of +0,02mm] than TI suggests)
2012-12-30 Minor mods, PA9-PA12 available on expansion connector
    [ruuvitracker.sch]
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2012-12-30 Replace 8xres arrays with 4xres arrays
    [ruuvitracker.sch]
2012-12-30 Add charger diodes, ferrite to MEMS MIC's power etc.
    [ruuvitracker.sch]
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2012-12-31 Add zener and remove schottkys
    [ruuvitracker.sch]
2012-12-31 Remove GSM's MIC, fix GSM's audio amp circuitry, own voltage divider for high_voltage input
    [ruuvitracker.sch]
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2013-01-01 Replace P-MOSFETs with load switches etc.
    [ruuvitracker.sch]
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2013-01-03 Revert back to P-MOSFET topology (USB voltage protection). Common-drain-pmos. Used often with the OTG.
    [ruuvitracker.sch]
2013-01-04 Minor fixes
    [ruuvitracker.sch]
2013-01-04 Remove OTG_CURRENT_LIMIT_SELECTION pin's pull-down resistor. Connect charger's status led's power to PMOS's source side.
    [ruuvitracker.sch]
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2013-01-06 Molex 1,25mm pitch connectors should fit both ways (reverse pin order)
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2013-01-07 Initial commit for RuuviTracker RevB's PCB layout design process
    [ruuvitracker.brd, ruuvitracker.sch]
2013-01-07 First components on the board
    [ruuvitracker.brd]
2013-01-08 More components on the board
    [ruuvitracker.brd, ruuvitracker.sch]
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2013-01-08 Change EMI shield's footprint and finish pcb outlines
    [ruuvitracker.brd]
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2013-01-09 Fix thru holes
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2013-01-09 Some progress, more components on the board etc.
    [ruuvitracker.brd]
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2013-01-09 Almost all components placed
    [ruuvitracker.brd]
2013-01-10 All components on the board, finetuning begins...
    [ruuvitracker.brd, ruuvitracker.sch]
2013-01-11 Fix footprint's NPTH
2013-01-11 More progress and few new test points
    [ruuvitracker.brd, ruuvitracker.sch]
2013-01-12 Some minor schema fixes and more pcb layour progress
    [ruuvitracker.brd, ruuvitracker.sch]
2013-01-12 IO expander pin changes etc.
    [ruuvitracker.brd, ruuvitracker.sch]
2013-01-12 Add DCDC's zones etc.
    [ruuvitracker.brd, ruuvitracker.sch]
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2013-01-13 Better uC's bypass cap positioning, gyro from top to bottom
    [ruuvitracker.brd]
2013-01-13 90ohm matched usb bus
    [ruuvitracker.brd, ruuvitracker.sch]
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2013-01-13 ID + MCU VBUS done
    [ruuvitracker.brd, ruuvitracker.sch]
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2013-01-13 Part of IO lines ready
    [ruuvitracker.brd, ruuvitracker.sch]
2013-01-13 More IO lines ready
    [ruuvitracker.brd, ruuvitracker.sch]
2013-01-14 All IO lines ready
    [ruuvitracker.brd]
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2013-01-16 Logos ok, few traces left, DRC almost passed
    [ruuvitracker.brd]
2013-01-16 DRC almost passed, few disconnected pins
    [ruuvitracker.brd, ruuvitracker.sch]
2013-01-16 DRC passed (one pin unconnected, but it's KiCad's bug)
    [ruuvitracker.brd]
2013-01-16 Move haptic driver's bypass caps
    [ruuvitracker.brd]
2013-01-16 Add GND zones to in1&2 layers
    [ruuvitracker.brd]
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2013-01-17 Make PCB look really awesome
    [ruuvitracker.brd]
2013-01-17 Add Netlight text. PCB order is on!
    [ruuvitracker.brd]
2013-01-18 100nF caps to 1uF
    [ruuvitracker.sch]
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2013-01-18 Change EEPROMs footprint from TSSOP8 to SO8N
    [ruuvitracker.brd, ruuvitracker.sch]
2013-01-30 Add comment about GSM_PWRKEY's states
    [ruuvitracker.sch]
2013-01-30 RevB draft#007 -> Rev.B1
    [ruuvitracker.sch]
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2013-12-01 started working on a simple breakout
    [rt_hirose_breakout.sch]
2013-12-01 add SWD connector, though the VCC might *not* be (even equivalent to) the STM32 VDD, which would be a major problem
    [rt_hirose_breakout.sch]
2013-12-01 The VCCs might not be the same, at least not in the future...
    [rt_hirose_breakout.sch]
2013-12-01 use solder jumpers to select which "vcc" pin to use for SWD VDD
    [rt_hirose_breakout.sch]
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2013-12-01 updated the df37 library changes
    [rt_hirose_breakout.sch]
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2014-01-30 added a note about how to patch the board for this
    [flashbutton.sch]
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
